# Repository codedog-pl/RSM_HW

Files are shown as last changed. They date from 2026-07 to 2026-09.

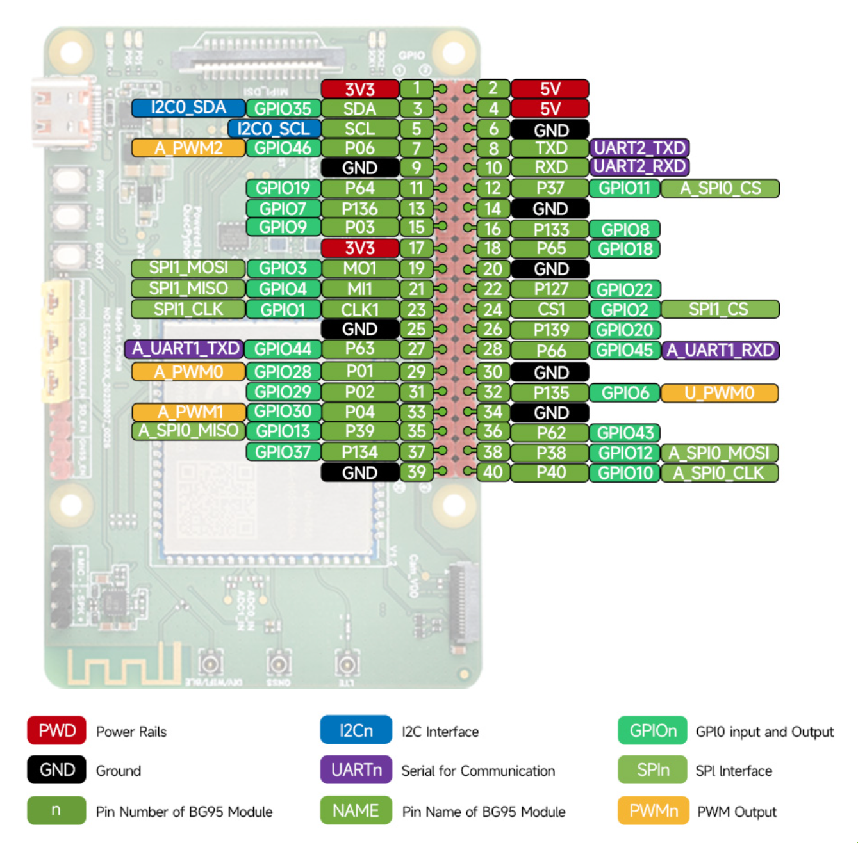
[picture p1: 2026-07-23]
Docs/EC200U-EU-C4-P01-pinout.png

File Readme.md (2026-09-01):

# Remote Sensors Module (HARDWARE)

## Folder structure
- *Docs* - datasheets and various documentation
- *KiCad* - Schematics and PCB
  - *CustomFootprints*
  - *CustomSymbols*
  - *RS* - **main KiCad project**
  - *Scripts* - Python helper scripts
- *Simulations* - CircuitJS simulations of functional blocks.
  
## Using Python scripts

To use Python scripts open the `KiCad` directory in Terminal.

### Re-annotate schematics with exiting PCB

- Assign UUIDs to schematics symbols:
  ```powershell
  python .\Scripts\assign_uuids.py .\RS 
  ```
- Open existing PCB and `Update PCB from schematics` to copy assigned UUIDs to the PCB file. **SAVE CHANGES!**
- Re-annotate the schematics, then **SAVE CHANGES!**
- Close both schematics and PCB views.
- Synchronize PCB footprint designators with schematics designators via UUIDs:
  ```powershell
  python .\Scripts\sync_designators.py .\RS
  ```
- Re-open schematics editor. `Update PCB from schematics` and
  **SAVE CHANGES** to rename nets using new designators.

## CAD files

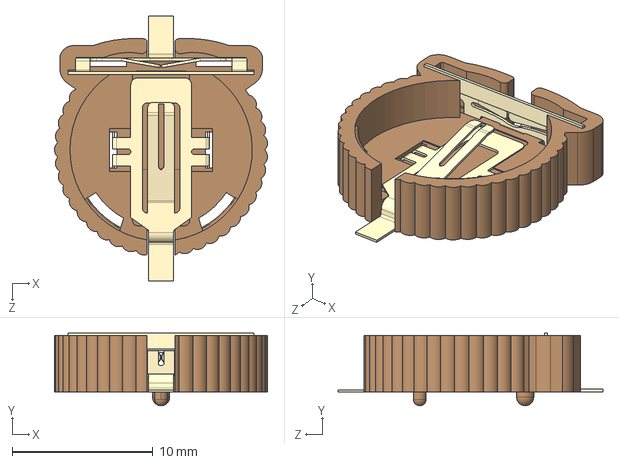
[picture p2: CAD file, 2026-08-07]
KiCad/CustomFootprints/1056.step
15.1 x 5.16 x 18.8 mm

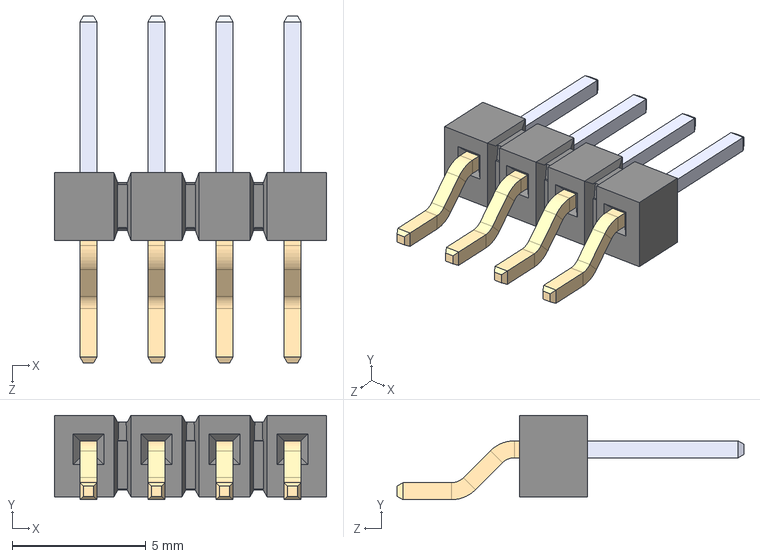
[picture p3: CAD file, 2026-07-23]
KiCad/CustomFootprints/TSM-104-01-L-SH.step
10.2 x 3.15 x 13.0 mm

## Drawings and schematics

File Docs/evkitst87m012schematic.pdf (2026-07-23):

# Ext. SUPPLY

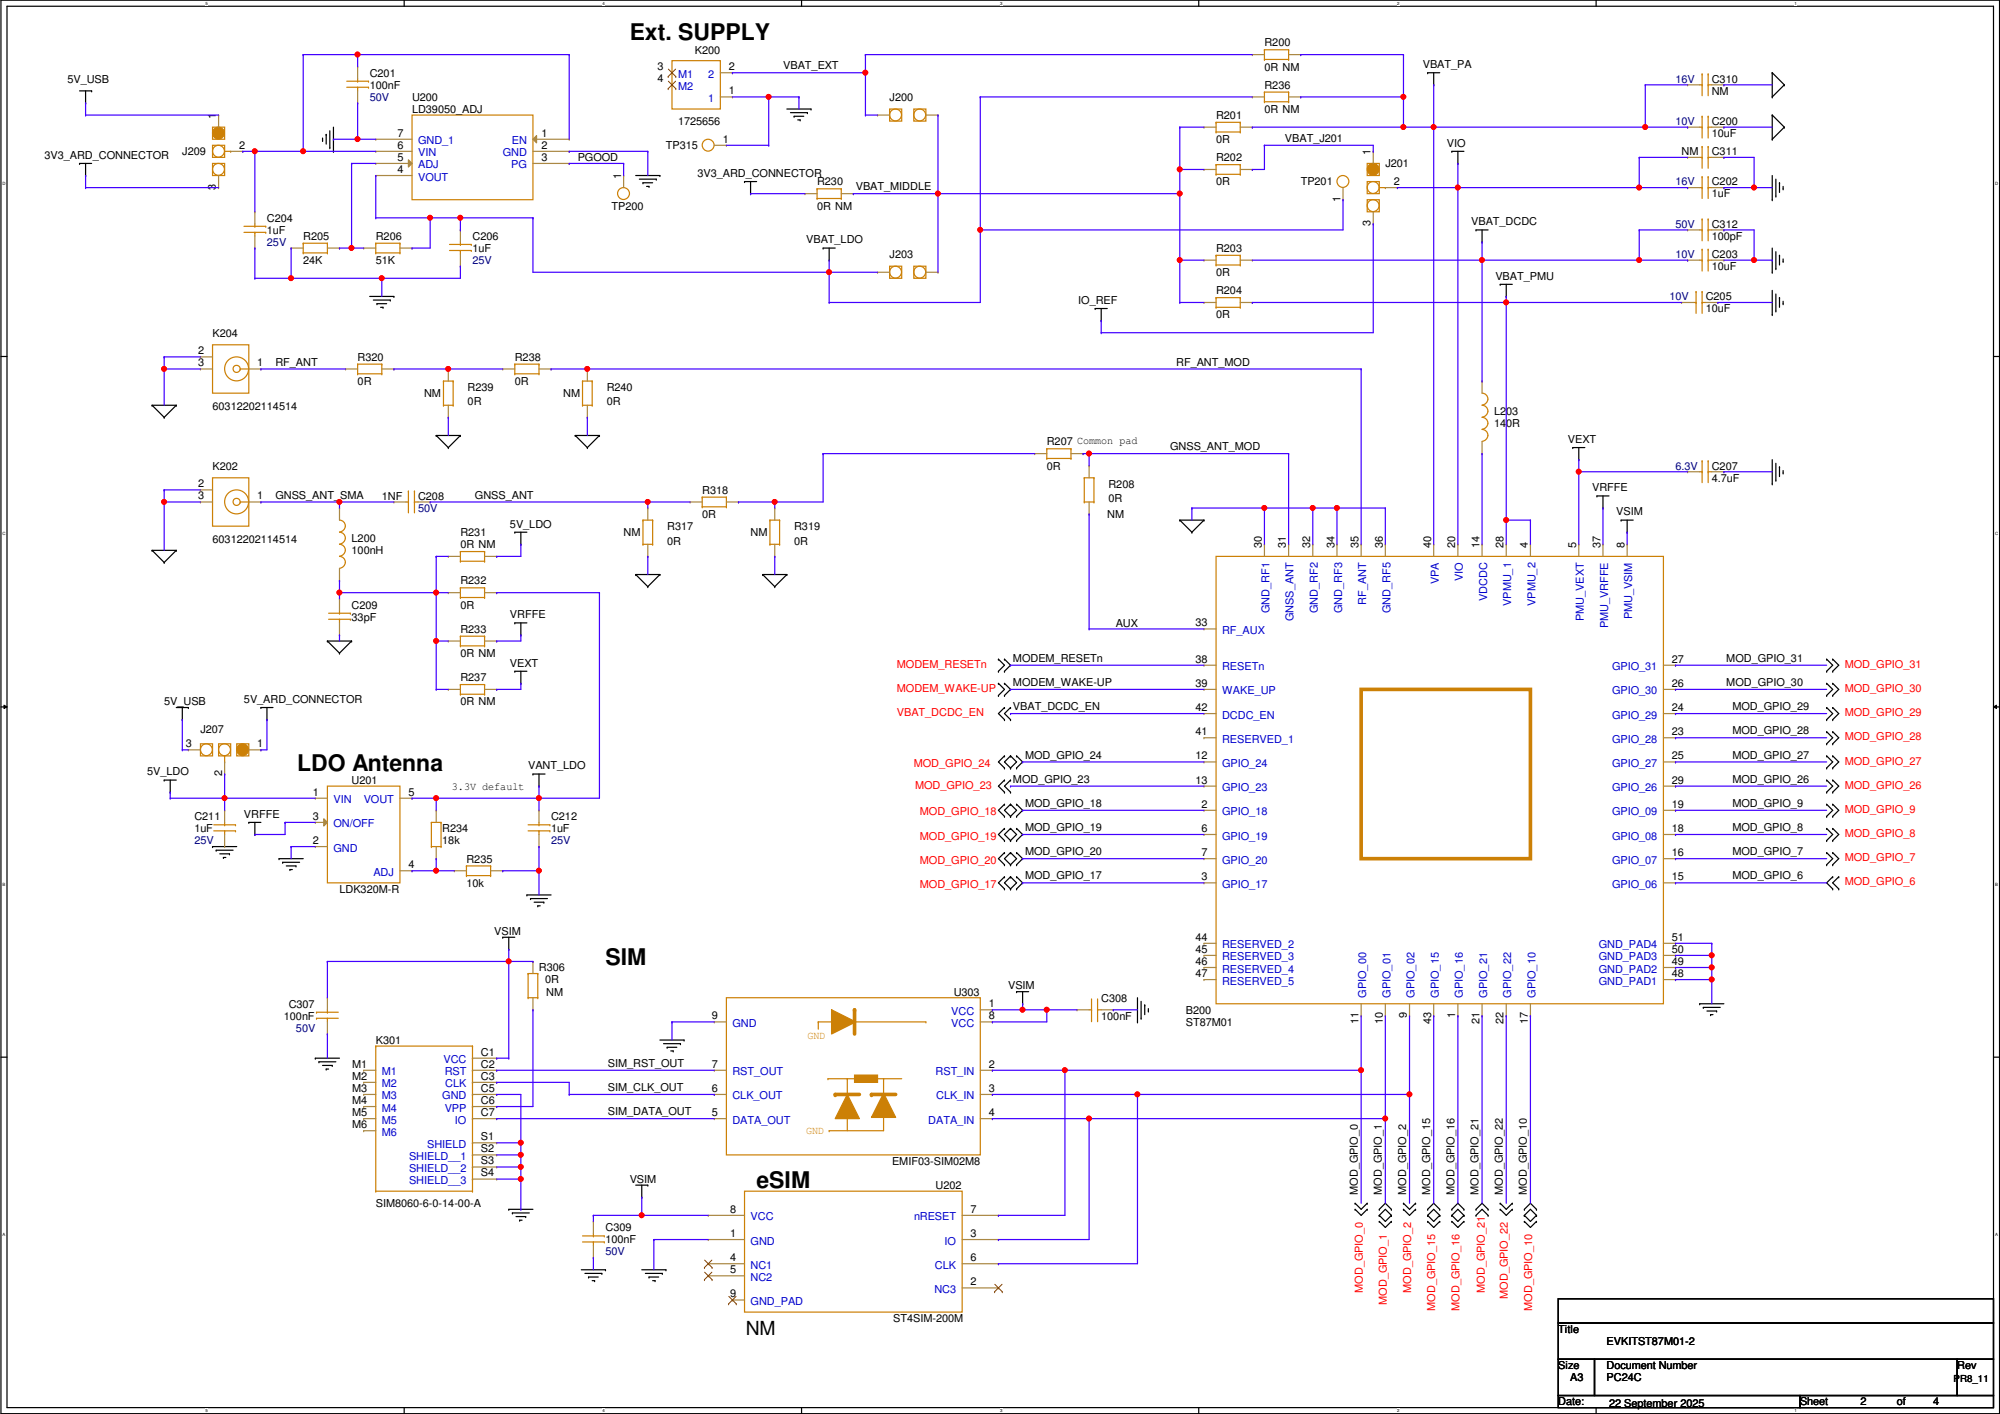
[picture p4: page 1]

VBAT_PMU

L203 140R | VEXT

## USB to UART converter

LED_RX | LED_TX

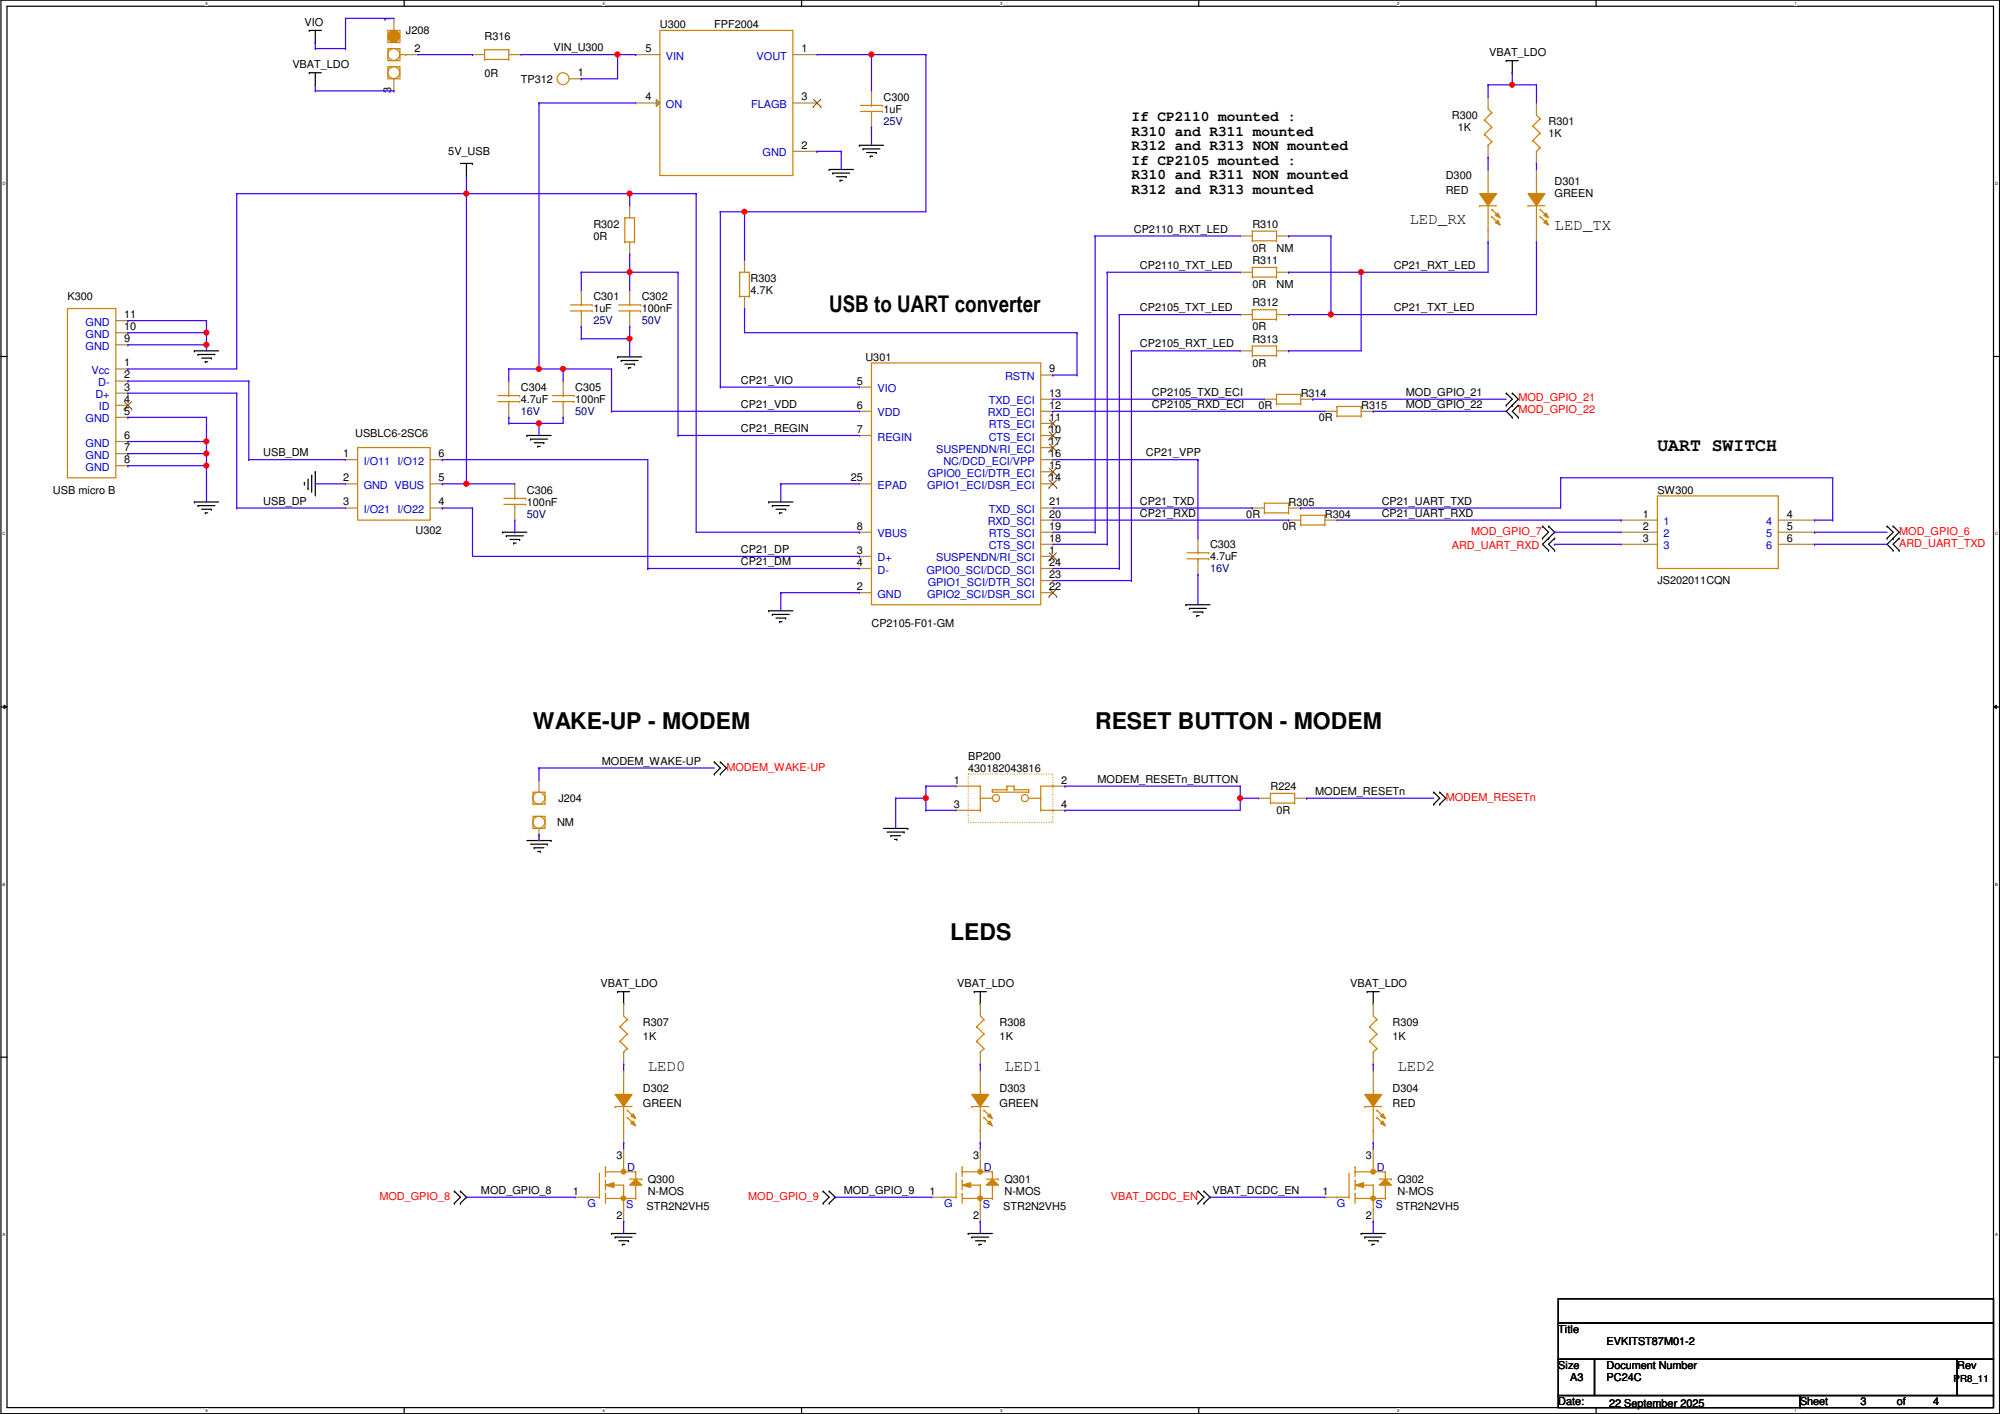
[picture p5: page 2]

CP21_TXD
CP21_RXD

# ARDUINO CONNECTORS

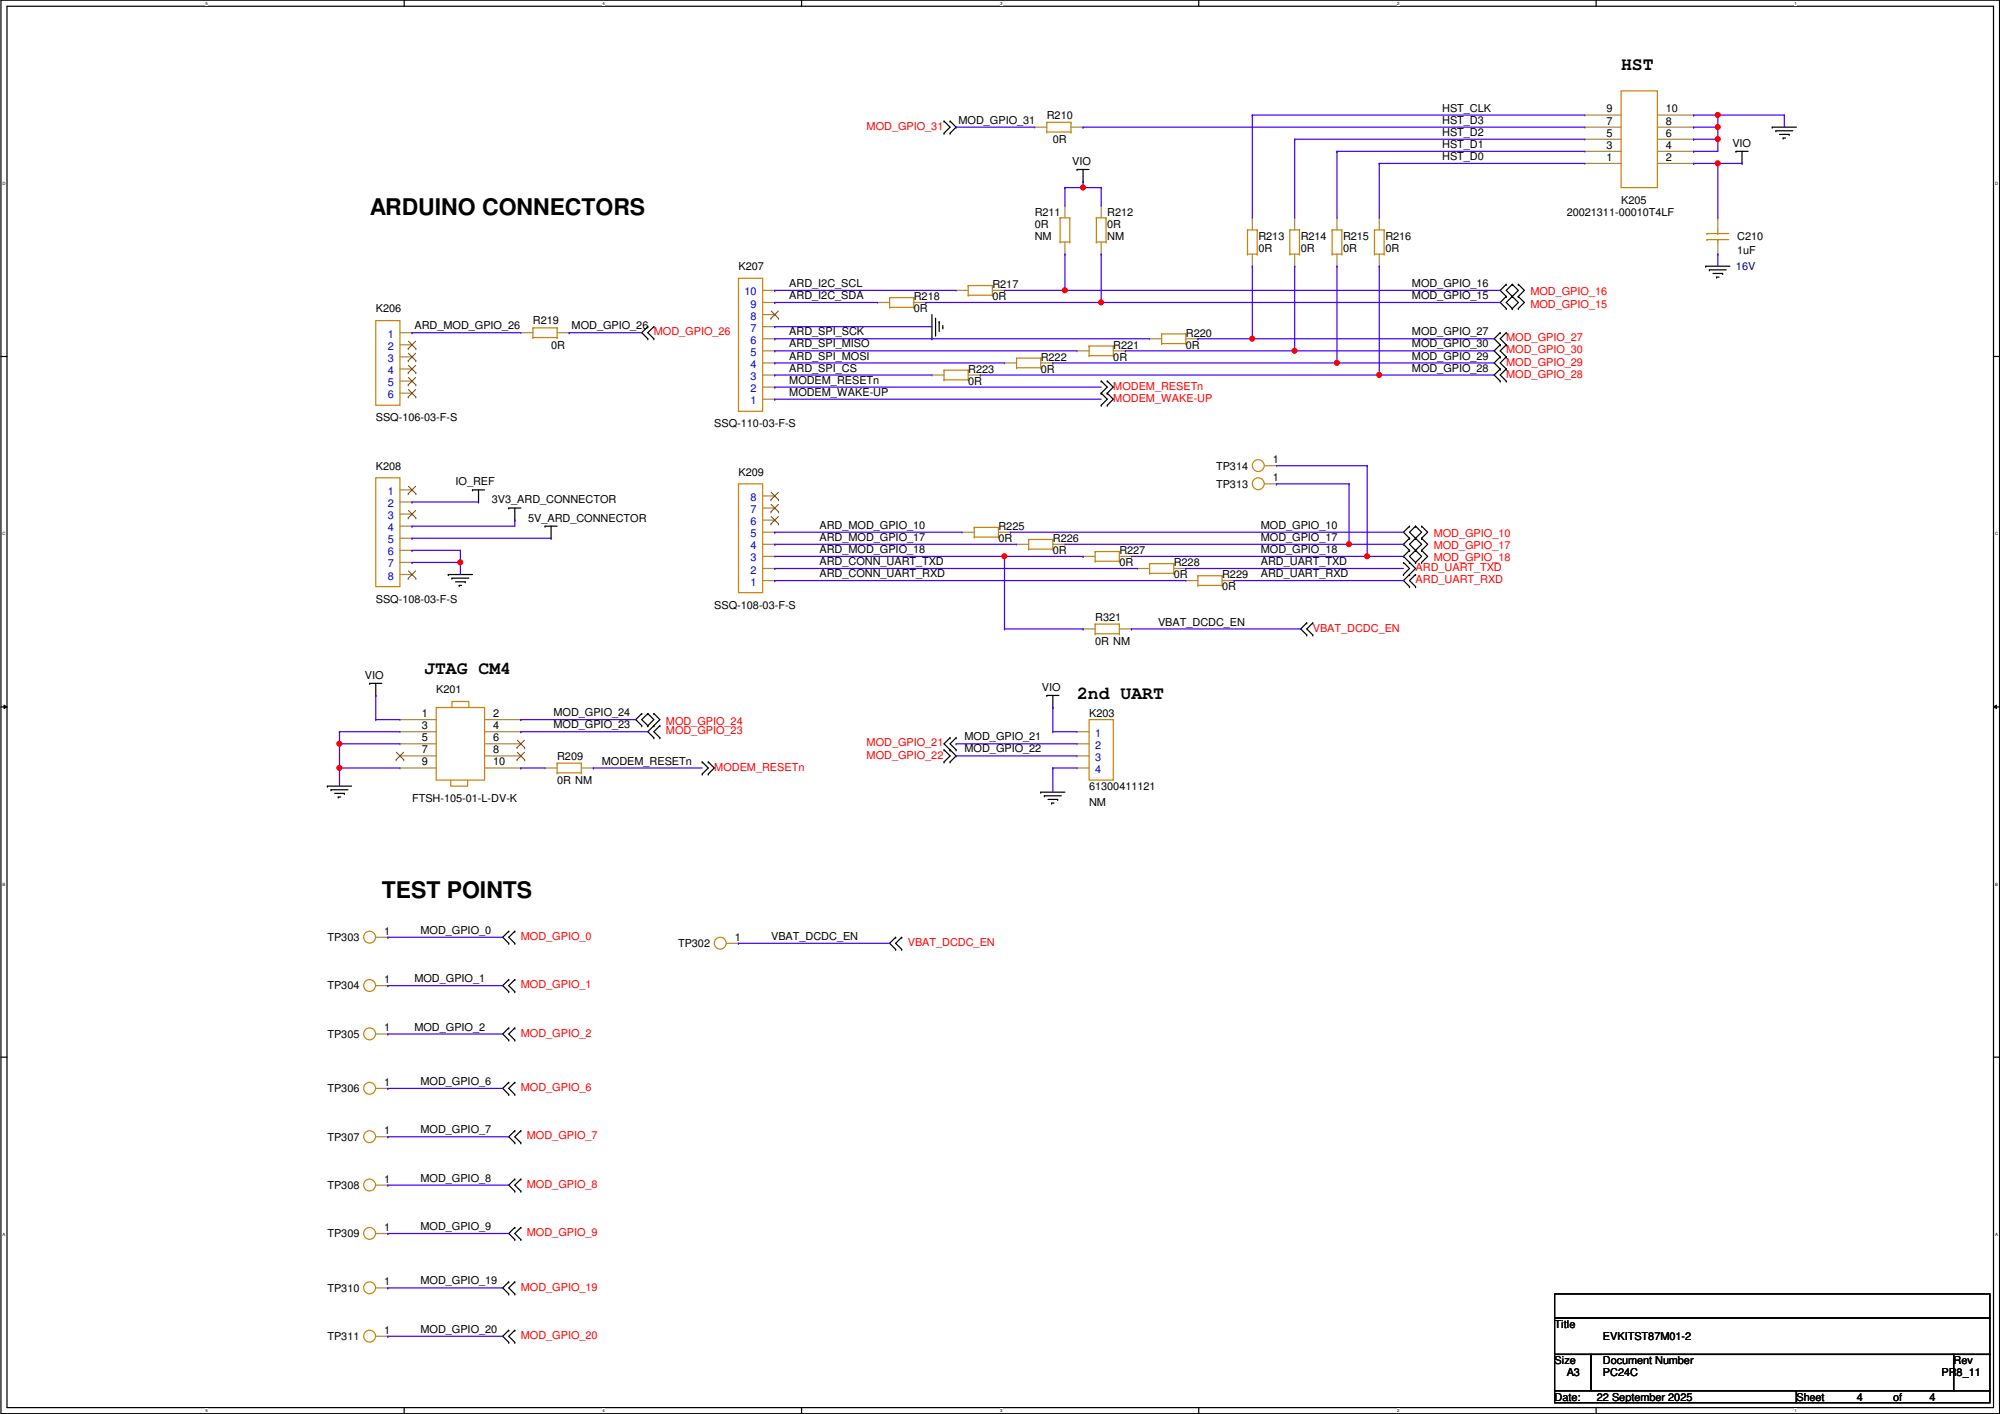
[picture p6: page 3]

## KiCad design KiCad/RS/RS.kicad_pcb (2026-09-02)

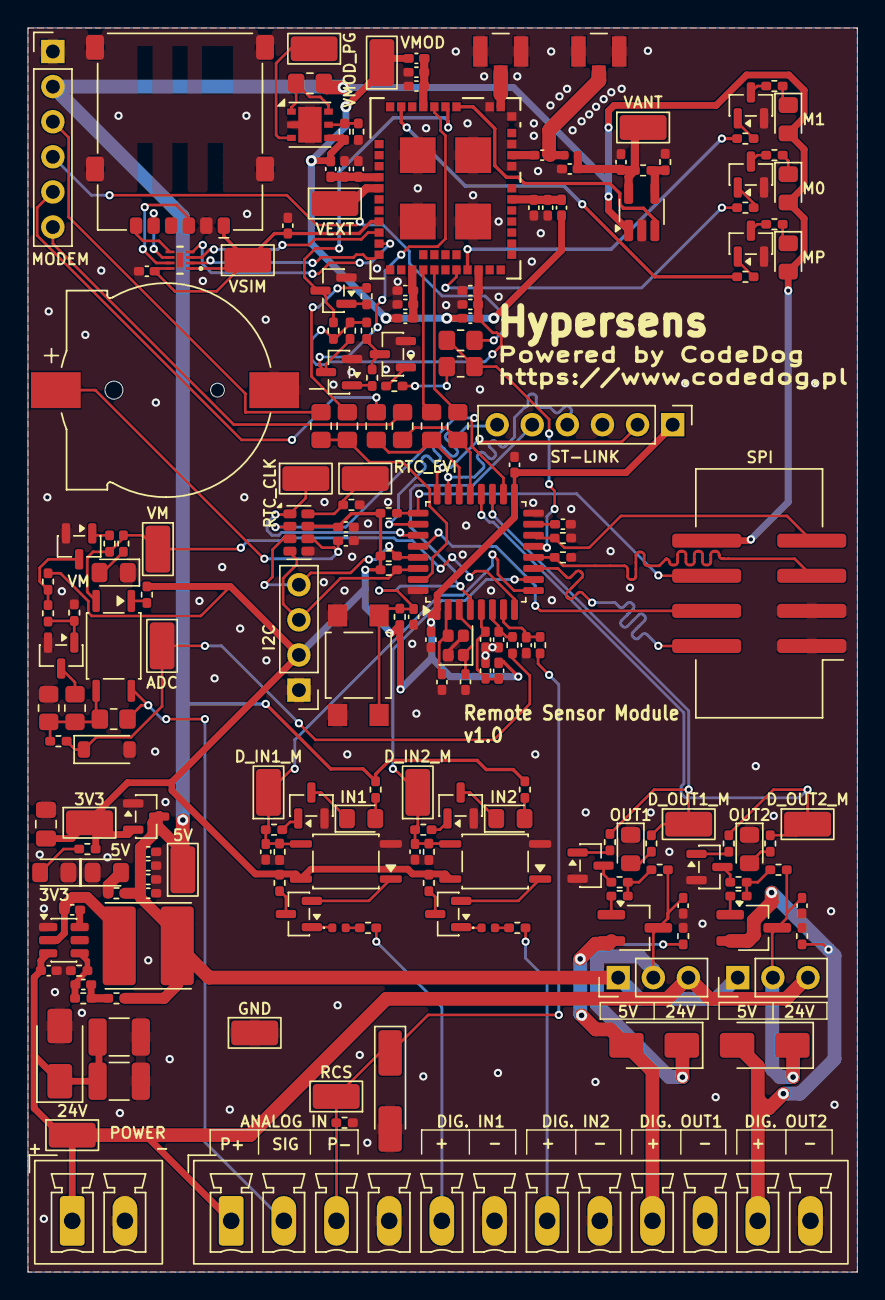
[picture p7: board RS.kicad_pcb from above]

Board: 2 copper layers, 60.0 x 90.0 mm, 197 parts (0 on the bottom side), 129 nets.

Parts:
BT1: 1056; BAT_1056
C1, C4, C6: 100n/50V; C_0402_1005Metric_Pad0.74x0.62mm_HandSolder
C2, C3: 10μ/50V; C_1210_3225Metric_Pad1.33x2.70mm_HandSolder
C5: 75pF/50V; C_0402_1005Metric_Pad0.74x0.62mm_HandSolder
C7, C8, C9, C22, C30, C32, C34, C36, C38: 10μ/10V; C_0402_1005Metric_Pad0.74x0.62mm_HandSolder
C10: 47μ/10V; C_0805_2012Metric_Pad1.18x1.45mm_HandSolder
C11, C13, C14, C18, C21, C23, C24, C25, C26, C27, C28, C29, C31, C33, C35, C37: 100n; C_0402_1005Metric_Pad0.74x0.62mm_HandSolder
C12, C19, C41: 1μ/10V; C_0402_1005Metric_Pad0.74x0.62mm_HandSolder
C15, C16: 12p; C_0402_1005Metric_Pad0.74x0.62mm_HandSolder
C17, C39: 1n; L_0402_1005Metric_Pad0.77x0.64mm_HandSolder
C20: 2μ2/10V; C_0402_1005Metric_Pad0.74x0.62mm_HandSolder
C40: 33p; C_0402_1005Metric_Pad0.74x0.62mm_HandSolder
D1: SMAJ26A; D_SMA
D2, D3, D15: LED red; D_0805_2012Metric_Pad1.15x1.40mm_HandSolder
D4: 1V; D_MiniMELF_Handsoldering
D5: 3V6; D_SOD-123
D6, D13, D14: LED orange; D_0805_2012Metric_Pad1.15x1.40mm_HandSolder
D7, D8: D_Schottky; D_0402_1005Metric
D9, D10, D16, D17: LED green; D_0805_2012Metric_Pad1.15x1.40mm_HandSolder
D11, D12: 1000V/1A; D_SMA
J1: 4.5-28V; PhoenixContact_MCV_1,5_2-G-3.81_1x02_P3.81mm_Vertical
J2: Screw_Terminal_01x12; PhoenixContact_MCV_1,5_12-G-3.81_1x12_P3.81mm_Vertical
J3: ST-LINK; PinHeader_1x06_P2.54mm_Vertical
J4: SPI; IDC-Header_2x04_P2.54mm_Vertical_SMD
J5: MODEM; PinHeader_1x06_P2.54mm_Vertical
J6: I2C; PinHeader_1x04_P2.54mm_Vertical
J7: GNSS; TE_1909763-1
J8: SIM; nanoSIM_GCT_SIM8060-6-0-14-00
J9: ANT.; TE_1909763-1
JP1, JP2: Jumper_3_Bridged12; PinHeader_1x03_P2.54mm_Vertical
L1: 15μH/2.05A; L_Cenker_CKCS6045
L2: 1kΩ/100MHz; L_0402_1005Metric_Pad0.77x0.64mm_HandSolder
L3, L4, L5, L6, L7: 120Ω/100MHz/2A; L_0402_1005Metric_Pad0.77x0.64mm_HandSolder
L8: 100nH; L_0402_1005Metric
Q1: AO3400A; SOT-23
Q2, Q3, Q4, Q5, Q6, Q9, Q10, Q11, Q12, Q13, Q14, Q15, Q16: BC817; SOT-23
Q7, Q8: P60V/2A; SOT-23W_Handsoldering
R1: 49R9; R_0402_1005Metric_Pad0.72x0.64mm_HandSolder
R2, R36, R37, R65, R66, R67: 180; R_0402_1005Metric_Pad0.72x0.64mm_HandSolder
R3, R30, R54, R55: 82; R_0402_1005Metric_Pad0.72x0.64mm_HandSolder
R4, R33, R42, R43, R52, R53: 100k; R_0402_1005Metric_Pad0.72x0.64mm_HandSolder
R5: 13k3; R_0402_1005Metric_Pad0.72x0.64mm_HandSolder
R6, R13, R19, R20, R26: 10k; R_0402_1005Metric_Pad0.72x0.64mm_HandSolder
R7, R8, R28, R32, R40, R41, R44, R45, R48, R49, R50, R51, R61, R62, R64: 4k7; R_0402_1005Metric_Pad0.72x0.64mm_HandSolder
R9, R10, R11, R12, R15, R17, R18, R21, R56: 0R; R_0805_2012Metric_Pad1.20x1.40mm_HandSolder
R14, R16: 2k; R_0402_1005Metric_Pad0.72x0.64mm_HandSolder
R22, R24, R27: 120; R_0402_1005Metric_Pad0.72x0.64mm_HandSolder
R23: 68k 0.1%; R_0805_2012Metric_Pad1.20x1.40mm_HandSolder
R25: 133 0.1%; R_0805_2012Metric_Pad1.20x1.40mm_HandSolder
R29: 200; R_0402_1005Metric_Pad0.72x0.64mm_HandSolder
R31: 27.7k 0.1%; R_0805_2012Metric_Pad1.20x1.40mm_HandSolder
R34, R35, R46, R47, R59, R60, R63, R69, R70, R71: 1k; R_0402_1005Metric_Pad0.72x0.64mm_HandSolder
R38, R39: 22k; R_0402_1005Metric_Pad0.72x0.64mm_HandSolder
R57: 51k 0.1%; R_0402_1005Metric_Pad0.72x0.64mm_HandSolder
R58: 24k 0.1%; R_0402_1005Metric_Pad0.72x0.64mm_HandSolder
R68: 18k 0.1%; R_0402_1005Metric_Pad0.72x0.64mm_HandSolder
R72: 10k 0.1%; R_0402_1005Metric_Pad0.72x0.64mm_HandSolder
SW1: SW_Push; SW_SPST_TL3305A
TP1: GND; TestPoint_Keystone_5015_Micro_Mini
TP2: 3V3; TestPoint_Keystone_5015_Micro_Mini
TP3: 5V; TestPoint_Keystone_5015_Micro_Mini
TP4: 24V; TestPoint_Keystone_5015_Micro_Mini
TP5: VMOD_PG; TestPoint_Keystone_5015_Micro_Mini
TP6: VMOD; TestPoint_Keystone_5015_Micro_Mini
TP7: VEXT; TestPoint_Keystone_5015_Micro_Mini
TP8: VSIM; TestPoint_Keystone_5015_Micro_Mini
TP9: VANT; TestPoint_Keystone_5015_Micro_Mini
TP10: ADC; TestPoint_Keystone_5015_Micro_Mini
TP11: RCS; TestPoint_Keystone_5015_Micro_Mini
TP12: VM; TestPoint_Keystone_5015_Micro_Mini
TP13: D_IN1_M; TestPoint_Keystone_5015_Micro_Mini
TP14: D_IN2_M; TestPoint_Keystone_5015_Micro_Mini
TP15: D_OUT1_M; TestPoint_Keystone_5015_Micro_Mini
TP16: D_OUT2_M; TestPoint_Keystone_5015_Micro_Mini
TP17: RTC_CLK; TestPoint_Keystone_5015_Micro_Mini
TP18: RTC_EVI; TestPoint_Keystone_5015_Micro_Mini
U1: MCP1700T-3302E/TT; SOT-23
U2: TPS54202; SOT-23-6
U3: STM32C562KET6; LQFP-32_7x7mm_P0.8mm
U4, U6, U7: TLP185; SOIC-4_4.55x3.7mm_P2.54mm
U5: RV-3028-C7; MicroCrystal_C7_SON-8_1.5x3.2mm_P0.9mm
U8: LD39050PUR; DFN-6-1EP_3x3mm_P0.95mm_EP1.7x2.6mm
U9: EMIF03-SIM02M8; MICROQFN_1P7X1P5_STM
U10: ST87M01-1301; LGA-51_10P6X12P8_STM
U11: LDK320M-R; SOT-23-5_HandSoldering
Y1: 24MHz CL=8pF ESR=50Ω; Crystal_SMD_2016-4Pin_2.0x1.6mm

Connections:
+3V3: C10.1, C13.2, C14.2, C21.2, J3.1, J6.2, L2.1, R3.2, R6.1, R7.1, R8.1, R13.1, R22.1, R28.1, R34.2, R35.2, TP2.1 (Pin_1_1), U1.2 (VO), U3.1 (VDD), U3.17 (VDD), U5.7 (VDD), U6.6, U7.6
+5V: C6.1, C7.1, C8.1, C9.1, D15.2 (A), D16.2 (A), D17.2 (A), J4.8, J5.2, JP1.1 (A), JP2.1 (A), L1.2, R1.1, R2.1, R36.1, R37.1, R56.2, TP3.1 (Pin_1_1), U1.3 (VI), U11.1 (VIN)
+24V: C2.1, C3.1, C4.1, D1.1 (A1), J1.1, J2.1, JP1.3 (B), JP2.3 (B), TP4.1 (Pin_1_1), U2.3 (VIN)
ADC: D5.1 (K), R14.1, R24.2, TP10.1 (Pin_1_1)
A_IN: J2.2, R23.2, U4.6
DCDC_EN: R69.1, U10.42 (DCDC_EN)
D_IN1: J2.5, R38.1
D_IN1_M: C23.1, R40.1, R42.1, TP13.1 (Pin_1_1), U3.9 (PA3), U6.4
D_IN2: J2.7, R39.1
D_IN2_M: C24.1, R41.1, R43.1, TP14.1 (Pin_1_1), U3.10 (PA4), U7.4
D_OUT1: D11.2 (A), J2.9, Q7.2 (S), R52.1
D_OUT1_M: R50.1, R54.2, TP15.1 (Pin_1_1), U3.19 (PA8)
D_OUT2: D12.2 (A), J2.11, Q8.2 (S), R53.1
D_OUT2_M: R51.1, R55.2, TP16.1 (Pin_1_1), U3.20 (PA9)
GND: BT1.N, C2.2, C3.2, C4.2, C6.2, C7.2, C8.2, C9.2, C10.2, C11.1, C12.1, C13.1, C14.1, C15.2, C16.2, C17.1, C18.1, C19.1, C20.1, C21.1, C22.1, C23.2, C24.2, C25.2, C26.2, C27.1, C28.1, C29.1, C30.1, C31.1, C32.1, C33.1, C34.1, C35.1, C36.1, C37.1, C38.1, C40.2, C41.2, D1.2 (A2), D2.1 (K), D3.1 (K), D4.2 (A), D5.2 (A), D6.1 (K), D13.1 (K), D14.1 (K), J1.2, J2.4, J2.6, J2.8, J2.10, J2.12, J3.3, J4.1, J4.3, J5.1, J6.1, J7.G1 (GND), J8.5 (GND), J8.SH, J9.G1 (GND), Q1.2 (S), Q2.2 (E), Q5.2 (E), Q6.2 (E), Q9.2 (E), Q10.2 (E), Q11.2 (E), Q12.2 (E), Q13.2 (E), Q14.2 (E), Q15.2 (E), Q16.2 (E), R5.1, R19.2, R20.2, R26.2, R27.1, R31.1, R33.2, R42.2, R43.2, R52.2, R53.2, R58.2, R72.2, SW1.1, TP1.1 (Pin_1_1), U1.1 (GND), U2.1 (GND), U3.16 (VSS), U3.32 (VSS), U5.5 (VSS), U6.3, U7.3, U8.2 (GND), U8.7 (GND), U9.9 (GND), U10.30 (GND_RF1), U10.32 (GND_RF2), U10.34 (GND_RF3), U10.36 (GND_RF5), U10.48 (GND_PAD1), U10.49 (GND_PAD2), U10.50 (GND_PAD3), U10.51 (GND_PAD4), U11.2 (GND), Y1.2 (G), Y1.4 (G)
I2C_SCL: J6.4, R7.2, U3.29 (PB6), U5.3 (SCL)
I2C_SDA: J6.3, R8.2, U3.30 (PB7), U5.4 (SDA)
MODEM_LED0: R70.1, U10.18 (GPIO_08)
MODEM_LED1: R71.1, U10.19 (GPIO_09)
MODEM_RST: R10.1, R64.1
MODEM_RX: R15.2, U10.15 (GPIO_06)
MODEM_TX: R17.2, U10.16 (GPIO_07)
MODEM_WAKE_UP: R18.2, R62.1
NRST: C18.2, J3.5, R13.2, SW1.2, U3.4 (NRST)
unnamed: C5.1, R1.2, R4.1
unnamed: D2.2 (A), R2.2
unnamed: D3.2 (A), R3.1
unnamed: D6.2 (A), R30.2
unnamed: D7.2 (A), R38.2
unnamed: D7.1 (K), Q3.1 (B)
unnamed: D8.2 (A), R39.2
unnamed: D8.1 (K), Q4.1 (B)
unnamed: D9.2 (A), R36.2
unnamed: D9.1 (K), Q5.3 (C)
unnamed: D10.2 (A), R37.2
unnamed: D10.1 (K), Q6.3 (C)
unnamed: C25.1, D11.1 (K), JP1.2 (C), Q7.3 (D), R44.1
unnamed: C26.1, D12.1 (K), JP2.2 (C), Q8.3 (D), R45.1
unnamed: D13.2 (A), R54.1
unnamed: D14.2 (A), R55.1
unnamed: D15.1 (K), R65.1
unnamed: D16.1 (K), R66.1
unnamed: D17.1 (K), R67.1
unnamed: C39.1, J7.1 (SIG), L8.1
unnamed: J8.3 (CLK), U9.6 (CLK_EXT)
unnamed: J8.7 (I/O), U9.5 (DATA_EXT)
unnamed: J8.2 (RST), U9.7 (RST_EXT)
unnamed: J9.1 (SIG), U10.35 (RF_ANT)
unnamed: Q1.3 (D), R25.1
unnamed: Q1.1 (G), R29.2, R33.1
unnamed: Q2.1 (B), R32.2
unnamed: Q2.3 (C), R28.2, R29.1
unnamed: Q3.3 (C), R34.1
unnamed: Q3.2 (E), U6.1
unnamed: Q4.3 (C), R35.1
unnamed: Q4.2 (E), U7.1
unnamed: Q5.1 (B), R40.2
unnamed: Q6.1 (B), R41.2
unnamed: Q7.1 (G), R46.2
unnamed: Q8.1 (G), R47.2
unnamed: Q9.1 (B), R50.2
unnamed: Q9.3 (C), R48.2
unnamed: Q10.1 (B), R51.2
unnamed: Q10.3 (C), R49.2
unnamed: Q11.1 (B), R61.2
unnamed: Q11.3 (C), R59.1, U10.39 (WAKE_UP)
unnamed: Q12.1 (B), R62.2
unnamed: Q12.3 (C), R60.1, R61.1
unnamed: Q13.1 (B), R64.2
unnamed: Q13.3 (C), R63.1, U10.38 (RESETn)
unnamed: Q14.1 (B), R69.2
unnamed: Q14.3 (C), R65.2
unnamed: Q15.1 (B), R70.2
unnamed: Q15.3 (C), R66.2
unnamed: Q16.1 (B), R71.2
unnamed: Q16.3 (C), R67.2
unnamed: R22.2, U4.1
unnamed: R23.1, R24.1, R25.2, R31.2, U4.4
unnamed: R44.2, R46.1, R48.1
unnamed: R45.2, R47.1, R49.1
unnamed: C1.2, U2.6 (BOOT)
unnamed: C5.2, R4.2, R5.2, U2.4 (FB)
unnamed: C1.1, L1.1, U2.2 (SW)
unnamed: C15.1, U3.2 (PH0-OSC_IN), Y1.3
unnamed: C16.1, U3.3 (PH1-OSC_OUT), Y1.1
unnamed: C20.2, U3.15 (VCAP)
unnamed: C11.2, C12.2, L2.2, U3.5 (VREF+)
unnamed: C19.2, R14.2, U3.6 (PA0)
unnamed: C17.2, R16.2, U3.7 (PA1)
unnamed: R18.1, R21.2, U3.13 (PA7)
unnamed: R12.1, R17.1, U3.21 (PA11)
unnamed: R11.1, R15.1, U3.22 (PA12)
unnamed: R9.1, R10.2, U3.31 (PB8-BOOT0)
unnamed: BT1.P, C22.2, U5.6 (VBACKUP)
unnamed: R57.2, R58.1, U8.5 (ADJ)
unnamed: R56.1, U8.1 (EN), U8.6 (VIN)
unnamed: C33.2, C34.2, L5.2, U10.14 (VDCDC)
unnamed: C29.2, C30.2, L3.2, U10.28 (VPMU_1)
unnamed: C31.2, C32.2, L4.2, U10.4 (VPMU_2)
unnamed: C39.2, U10.31 (GNSS_ANT)
unnamed: C37.2, C38.2, L7.2, U10.40 (VPA)
unnamed: U9.2 (RST_IN), U10.11 (GPIO_00)
unnamed: U9.4 (DATA_IN), U10.10 (GPIO_01)
unnamed: U9.3 (CLK_IN), U10.9 (GPIO_02)
unnamed: R68.2, R72.1, U11.4 (ADJ)
RCS: D4.1 (K), J2.3, R16.1, R27.2, TP11.1 (Pin_1_1)
RTC_CLK: TP17.1 (Pin_1_1), U3.27 (PB4), U5.1 (CLKOUT)
RTC_EVI: R26.1, TP18.1 (Pin_1_1), U5.8 (EVI)
RTC_IRQ: U3.18 (PB15), U5.2 (~INT)
SPI_IRQ: J4.7, R20.1, U3.14 (PB0)
SPI_MISO: J4.5, R19.1, U3.12 (PA6)
SPI_MOSI: J4.4, U3.28 (PB5)
SPI_NSS: J4.6, R6.2, U3.25 (PA15)
SPI_SCK: J4.2, U3.11 (PA5)
SWCLK: J3.2, U3.24 (PA14)
SWDIO: J3.4, U3.23 (PA13)
SWO: J3.6, U3.26 (PB3)
VANT: C40.1, C41.1, L8.2, R68.1, TP9.1 (Pin_1_1), U11.5 (VOUT)
VEXT: TP7.1 (Pin_1_1), U10.5 (PMU_VEXT)
VM: R30.1, R32.1, TP12.1 (Pin_1_1), U3.8 (PA2), U4.3
VMOD: L3.1, L4.1, L5.1, L6.1, L7.1, R57.1, TP6.1 (Pin_1_1), U8.4 (VOUT)
VMOD_PG: TP5.1 (Pin_1_1), U8.3 (PG)
VMOD_VIO: C35.2, C36.2, L6.2, R59.2, R60.2, R63.2, U10.20 (VIO)
VRFFE: U10.37 (PMU_VRFFE), U11.3 (EN)
VSIM: C27.2, C28.2, J8.1 (VCC), TP8.1 (Pin_1_1), U9.1 (VCC), U9.8 (VCC), U10.8 (PMU_VSIM)
X_MODEM_RST: J5.3, R9.2
X_MODEM_RX: J5.5, R11.2
X_MODEM_TX: J5.6, R12.2
X_MODEM_WAKE_UP: J5.4, R21.1

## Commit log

2026-07-23 ADD: Project files.
    [RS.kicad_pcb, RS.kicad_sch, TSM-104-01-L-SH--3DModel-STEP-56544.STEP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]
2026-07-24 ADD: ST87M01-1301 Modem.
    [RS.kicad_sch, nbiot.kicad_sch]
2026-07-25 ADD: U.FL sockets.
2026-07-25 ADD: U.FL sockets circuits.
    [nbiot.kicad_sch]
2026-08-07 FIX: BOM, SCH.
    [1056.step, RS.kicad_sch, io-connectors.kicad_sch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]
2026-08-10 ADD: Connectors placement.
    [RS.kicad_pcb, io-connectors.kicad_sch]
2026-08-10 ADD: RF connections.
    [RS.kicad_pcb, RS.kicad_sch, io-connectors.kicad_sch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]
2026-08-11 FIX: 0805 to 0402, modem leds+drivers
    ADD: Modem part completed!
    [RS.kicad_pcb, RS.kicad_sch, io-connectors.kicad_sch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]
2026-08-11 ADD: BC817 LED driver simulation.
2026-08-13 ADD: STM32C562KET6 datasheet.
2026-08-13 ADD: Inductor footprint.
2026-08-13 ADD: Power calculator.
    [calculator.ods]
2026-08-13 FIX: Schematics + BOM.
    [RS.kicad_sch, io-connectors.kicad_sch, nbiot.kicad_sch]
2026-08-13 ADD: New PCB.
    [RS.kicad_pcb]
2026-08-15 FIX: Everything. 1.0.
    [RS.kicad_pcb, RS.kicad_sch, io-connectors.kicad_sch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]
2026-09-01 FIX: Schematics and simulation update.
    [RS.kicad_sch, io-connectors.kicad_sch]
2026-09-01 FIX: PCB completed.
    [RS.kicad_pcb]
2026-09-01 FIX: All PCB errors.
    Also, LD3905 symbol is changed, to have pin 7 as additional GND required.
    [RS.kicad_pcb, nbiot.kicad_sch]
2026-09-01 FIX: KiCad helper scripts to safely annotate existing PCB.
2026-09-01 ADD: UUID fields for all elements.
    [RS.kicad_sch, io-connectors.kicad_sch, nbiot.kicad_sch]
2026-09-01 ADD: UUIDs for all footprints.
    [RS.kicad_pcb]
2026-09-01 FIX: Re-annotate schematics.
    [RS.kicad_sch, io-connectors.kicad_sch, nbiot.kicad_sch]
2026-09-01 FIX: New designators synchronized.
    [RS.kicad_pcb]
2026-09-01 FIX: Net names changed to match new designators.
    [RS.kicad_pcb]
2026-09-02 FIX: Warnings, other.
    [RS.kicad_pcb, RS.kicad_sch, io-connectors.kicad_sch]
2026-09-02 FIX: Missing BOM fields.
    [RS.kicad_sch]
2026-09-03 FIX: BOM sort order.

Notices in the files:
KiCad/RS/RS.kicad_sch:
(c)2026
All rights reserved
